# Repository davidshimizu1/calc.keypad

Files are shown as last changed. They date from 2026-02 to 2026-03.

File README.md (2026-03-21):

# Custom Calculator & Bluetooth Macropad



A portable 25-key embedded device built around the **ESP32-S3-WROOM-1-N8R8**, combining a scientific calculator, a fully customizable Bluetooth HID macropad, and real-time weather display — all on a single custom PCB with a 3D-printed enclosure.

---

## Features
- **Scientific Calculator** — Full expression evaluation via custom GUI
- **Bluetooth HID Macropad** — 25 keys with 47 fully customizable macro bindings via BLE
- **Real-Time Weather** — Fetches live temperature data from OpenWeatherMap over Wi-Fi
- **Dual-Radio** — Simultaneous Wi-Fi and BLE operation on a single board
- **3.5" HMI Display** — 480×320 touchscreen driven via UART with mode switching
- **LiPo Battery** — Onboard charging circuit with deep-sleep power optimization
- **<4ms HID Latency** — Interrupt-driven key matrix scanning for instantaneous input

---

---

## Demo

### Calculator Mode
https://github.com/user-attachments/assets/d92eaae9-ccc6-4540-ab36-3ccdf94c4ab0

### Macropad Mode
https://github.com/user-attachments/assets/1930882c-5ee2-4487-85e7-eceab5c94025

---

## Hardware

### Core Components
| Component | Details |
|---|---|
| MCU | ESP32-S3-WROOM-1-N8R8 (8MB Flash, 8MB PSRAM) |
| Display | 3.5" 480×320 HMI (UART) |
| Switches | Kalih Choc V1 Ambient Silent |
| Battery | 1000mAh LiPo battery|
| PCB | Custom 4-layer, designed in Altium Designer |
| Enclosure | Multi-part 3D printed (PA12-HP Nylon) |
| Display Module | https://www.buydisplay.com/3-5-inch-480x320-hmi-intelligent-smart-uart-spi-touch-ips-tft-lcd-display |
| *All PCB and 3D printed parts from JLCPCB.com |

### PCB Design
- 4-layer stackup with dedicated power and ground planes
- RF keep-out zones around ESP32-S3 antenna to prevent detuning
- Integrated LiPo charging circuit

📁 Altium design files available in `/PCB`

---

## Firmware Architecture

The firmware is structured as a **main file + multiple custom libraries**, each handling a distinct subsystem:

```
/
├── src/
│   └── main.cpp              # Main file, calls the libraries
├── lib/
│   ├── Calculator/           # Scientific calculator logic
│   ├── Keypad/               # Scans key matrix & BLE HID profile 
│   ├── NetworkManagement/    # Handles, BLE, WiFi, weather, and time
│   ├── Display/              # UART HMI display & GUI state machine
│   └── PowerManagement/      # Handles power management
├── lib/
│   ├── Config/               # Contains pin definitions, addresses and variables
```

### Key Design Decisions
- **Non-blocking architecture** — Wi-Fi REST requests and BLE HID run concurrently without latency interference
- **Interrupt-driven matrix scanning** — Achieves <4ms HID response time while minimizing CPU overhead
- **Deep-sleep optimization** — Reduces idle power draw to extend battery life
- **Modular state machine** — GUI toggles cleanly between calculator and macropad modes

---

## Technical Highlights

### RF Design
The ESP32-S3-WROOM-1 module requires careful PCB layout to maintain antenna performance. This design implements:
- Localized copper keep-out zones beneath the module antenna
- Dedicated RF ground plane on inner layer 2
- Physical separation of noisy switching circuits from the RF section

### Power Management
- Deep-sleep triggered after configurable idle timeout
- LiPo charging via onboard circuit (add IC part number here)
- Interrupt-driven wake from any keypress

### Display Communication
The HMI display is driven over UART using a custom GUI subsystem that manages two distinct screen states — calculator mode and macropad mode — with clean transitions between them.

---

## Project Structure
```
/
├── 3D_models/          # Fusion 360 CAD files (.step, .stl)
├── Code/               # All code for project
├── fab/                # fabrication files for PCB production
├── pcb/                # Schematic and PCB files
└── README.md
```

---

## Built With
- [Visual Studio Code](https://code.visualstudio.com/) / PlatformIO
- [Altium Designer](https://www.altium.com/) — PCB design
- [Fusion 360](https://www.autodesk.com/products/fusion-360/) — Enclosure design
- [UI Editor](https://www.buydisplay.com/3-5-inch-480x320-hmi-intelligent-smart-uart-spi-touch-ips-tft-lcd-display) - Design UI (specific for this display)
- [OpenWeatherMap API](https://openweathermap.org/api) — Weather data

---

## Author
**David Shimizu**
[LinkedIn](https://linkedin.com/in/davidshimizu) · [GitHub](https://github.com/davidshimizu1)

<!--
![IMG_0332](https://github.com/user-attachments/assets/3b640d5e-4a3a-493a-8fa4-46986a46d832)

https://github.com/user-attachments/assets/d92eaae9-ccc6-4540-ab36-3ccdf94c4ab0

https://github.com/user-attachments/assets/1930882c-5ee2-4487-85e7-eceab5c94025

![comparison](https://github.com/user-attachments/assets/92db343a-2714-455a-88ce-03647a39ccdb)

![sidecomparison](https://github.com/user-attachments/assets/7a27574d-f005-4f37-92e9-b8760f2ecc49)
-->

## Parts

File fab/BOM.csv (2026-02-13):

Comment | Description | Designator | Footprint | LibRef | Quantity | LCSC Part #
10uF | 0402 smd capacitor | C1, C5 | 0402 capacitor | 0402 capacitor | 2 | C15525
22uF | 0402 smd capacitor | C2, C3 | 0402 capacitor | 0402 capacitor | 2 | C105226
4u7 | 0402 smd capacitor | C4 | 0402 CAPACITOR | 0402 capacitor | 1 | C23733
10uF |  | C6, C7, C8 | 0603 CAPACITOR | 0603 capacitor | 3 | C19702
100nF | 0402 smd capacitor | C9, C10 | 0402 CAPACITOR | 0402 capacitor | 2 | C1525
SOD-323 | 1N4148WS | D1, D2, D3, D4, D5, D6, D7, D8, D9, D10, D11, D12, D13, D14, D15, D16, D17, D18, D19, D20, D21, D22, D23, D24, D25 | SOD-323 | SOD-323 | 25 | C2128
RLED | Red 0603 Light Emitting Diodes | D26, D28 | LED_KT-0603R | KT-0603R | 2 | C2286
SMF5.0AT1G | 200 W Transient Voltage Suppressor, 2-Pin SOD-123FL, Pb-Free, Tape and Reel | D27 | ONSC-SOD-123FL-2-498_V | CMP-1061-00612-1 | 1 | C19077497
SS14 | 40V Independent Type 1A 550mV@1A SMA(DO-214AC) Schottky Diodes ROHS | D29 | SMA(DO-214AC)(SCHOTTKY) | ss14 | 1 | C8678
ESP32-S3-WROOM-1-N8R8 |  | IC1 | ESP32-S3-WROOM-1-N8R8 | ESP32-S3-WROOM-1-N8R8 | 1 | C2913201
TP4056X | Integrated Circuit | IC2 | SOIC127P600X175-9N | TP4056X | 1 | C16581
TPS61023DRLR | Integrated Circuit | IC3 | SOTFL50P160X60-6N | TPS61023DRLR | 1 | C919459
battery connector |  | J1 | 2PIN WIRE TO BOARD | 2pin wire to board | 1
503480-2000 | 0.5 mm Pitch Easy-On(TM) BackFlip(TM) Type FPC Connector, 1.0 mm Mated Height, Right Angle, SMT, Dual Contact, 20 Circuits, -40 to 85 degC, ELV and RoHS Compliant, Tape and Reel | J2 | MOLX-503480-2000 | CMP-1241-00121-1 | 1 | C234192
2.2uH |  | L1 | 0603 INDUCTOR | 0603 inductor | 1 | C98327
1uH |  | L2 | 0802 inductor | 0805 inductor | 1 | C1042
m2 mounting hole |  | MH1, MH2, MH3, MH4, MH5 | m2 mounting hole | m2 mounting hole | 5
AO3401A | P-Channel MOSFET, 30 V, 4 A, -55 to 150 degC, 3-Pin SOT-23-3L, RoHS, Tape and Reel | Q2 | AO-SOT-23-3L_V | CMP-2000-05778-1 | 1 | C15127
4k7 |  | R1, R2, R3, R4, R5 | 0603 RESISTOR | 0603 resistor | 5 | C23162
732K |  | R6 | 0402 resistor | 0402 resistor | 1 | C5159692
100K |  | R7 | 0402 resistor | 0402 resistor | 1 | C25741
10K |  | R8, R14, R15, R16, R19 | 0603 RESISTOR | 0603 resistor | 5 | C25804
1K |  | R9, R17 | 0402 RESISTOR | 0402 resistor | 2 | C11702
100K |  | R10 | 0603 RESISTOR | 0603 resistor | 1 | C25803
5K1 |  | R11, R12 | 0603 RESISTOR | 0603 resistor | 2 | C23186
22K |  | R13 | 0603 RESISTOR | 0603 resistor | 1 | C31850
1k2 |  | R18 | 0603 RESISTOR | 0603 resistor | 1 | C22765
switch |  | SW1, SW2, SW3, SW4, SW5, SW6, SW7, SW8, SW9, SW10, SW11, SW12, SW13, SW14, SW15, SW16, SW17, SW18, SW19, SW20, SW21, SW22, SW23, SW24, SW25 | CHOCV1 | switch | 25
push button |  | SW26, SW27 | PUSH BUTTON | push button | 2 | C318884
TLV62569DBVR | IC REG BUCK ADJ 2A SOT23-5 | U1 | FP-DBV0005A-MFG | CMP-04918-000387-1 | 1 | C141836
usbc connector |  | USB1 | USBC CONNECTOR | usbc connector | 1 | C2765186
USBLC6-2SC6 |  | X1 | STM-SOT23-6L_V | USBLC6-2SC6 | 1 | C7519

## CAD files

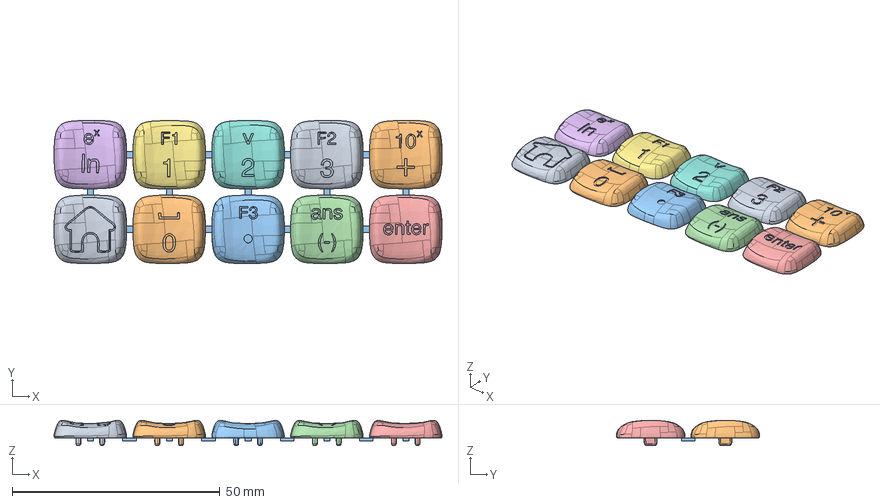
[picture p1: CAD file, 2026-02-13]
3d_models/ROW 1 ROW 2.step
93.5 x 34.5 x 6.10 mm
blank v3
blank v3_1
blank v3_2
blank v3_3
blank v3_4
blank v3_5
blank v3_6
blank v3_7
blank v3_8

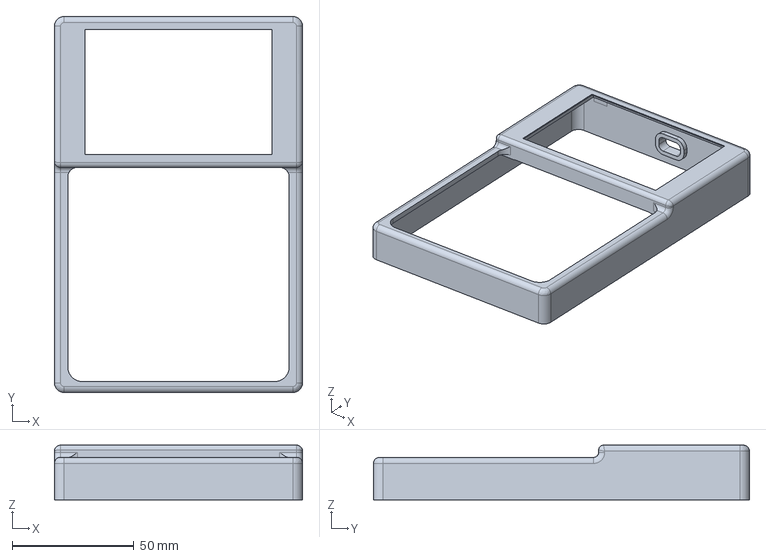
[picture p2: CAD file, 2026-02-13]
3d_models/top.step
102.0 x 154.5 x 22.5 mm

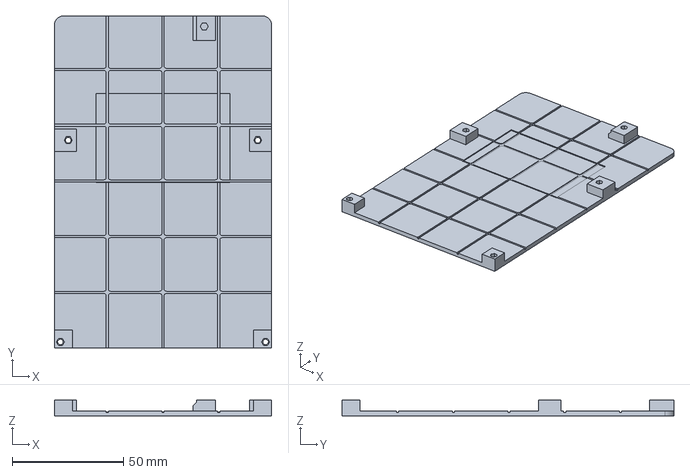
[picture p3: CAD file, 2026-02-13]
3d_models/bottom.step
97.4 x 148.9 x 7.10 mm

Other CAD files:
3d_models/ROW 5 BLANK ROW.step
3d_models/ROW 3 ROW 4 .step
3d_models/bottom.stl
3d_models/top.stl

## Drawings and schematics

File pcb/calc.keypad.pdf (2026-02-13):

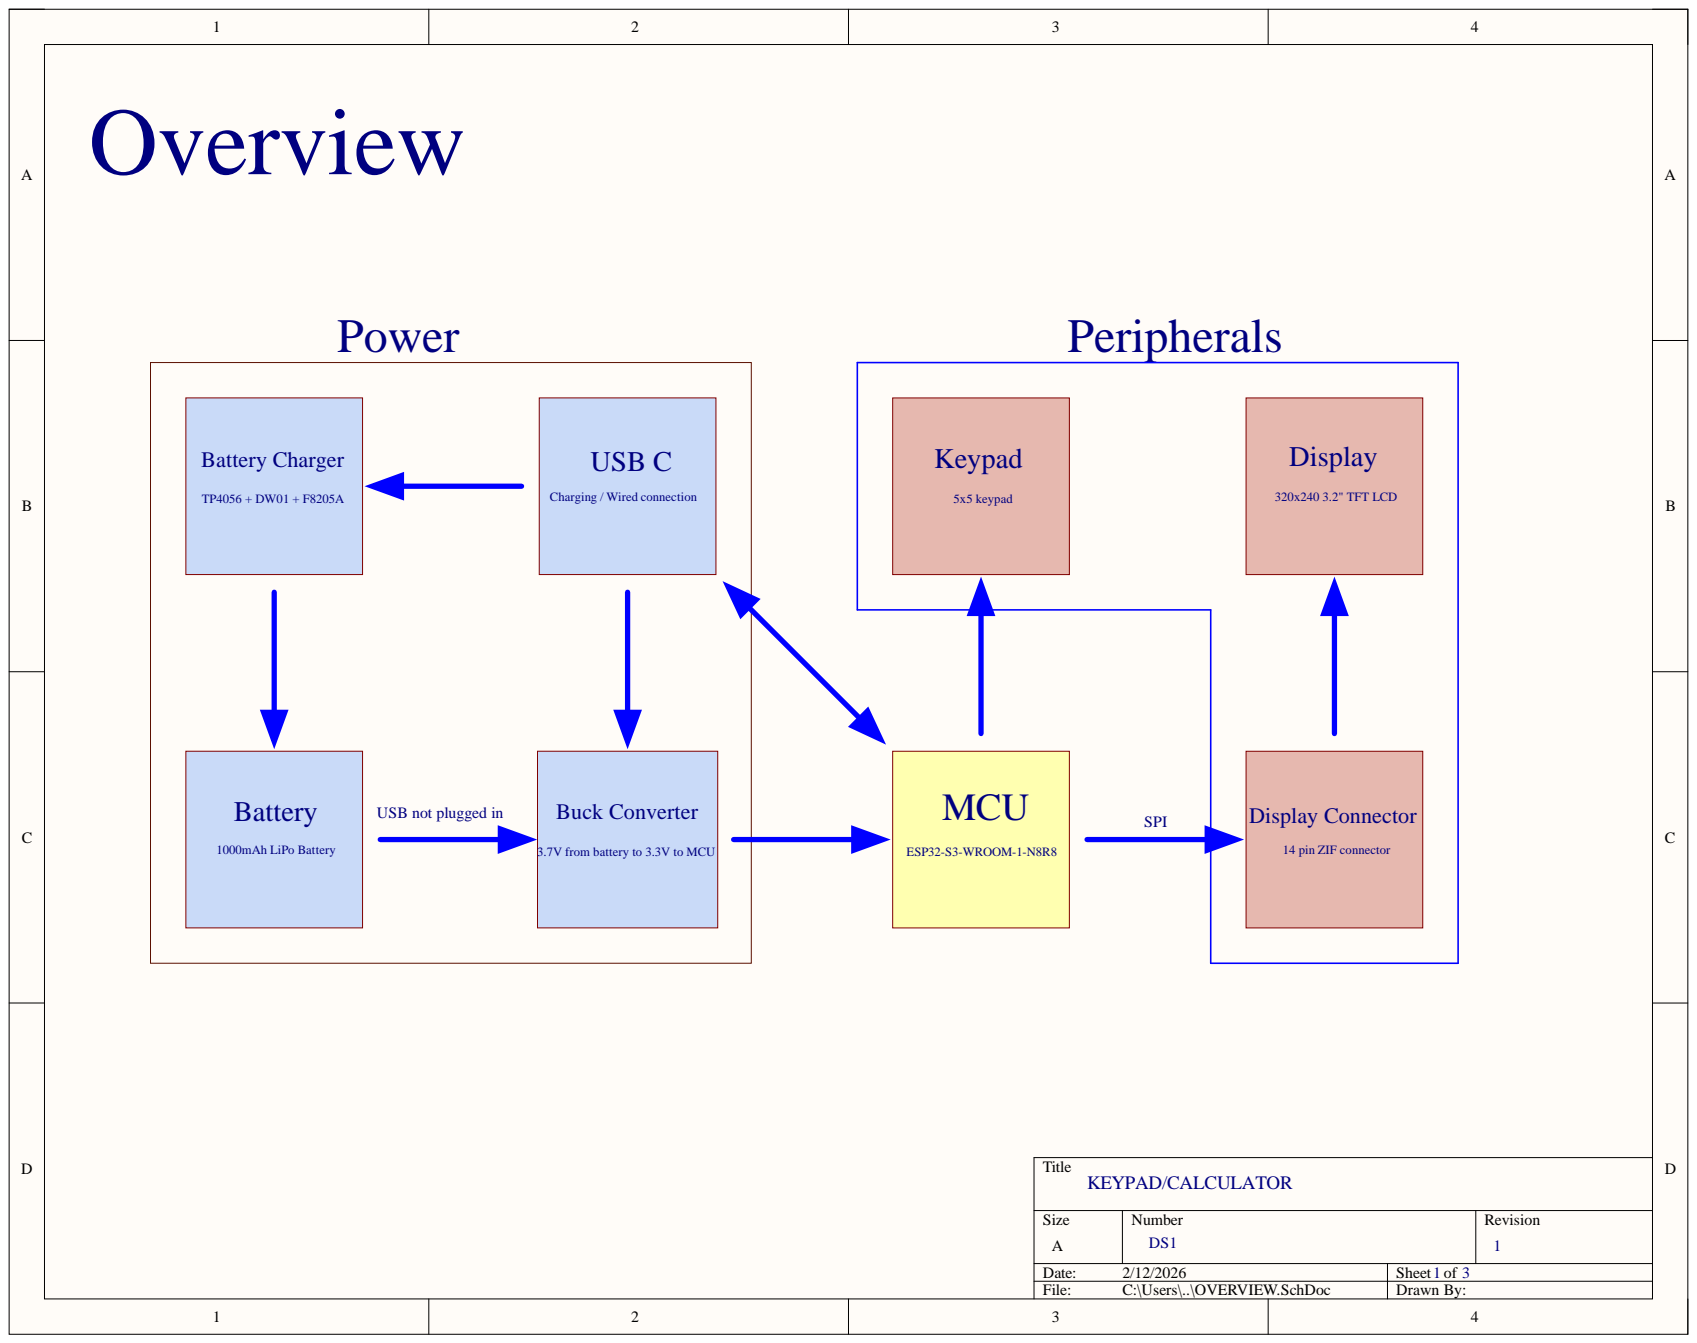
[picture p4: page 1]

USB not plugged in

3.7V from battery to 3.3V to MCU

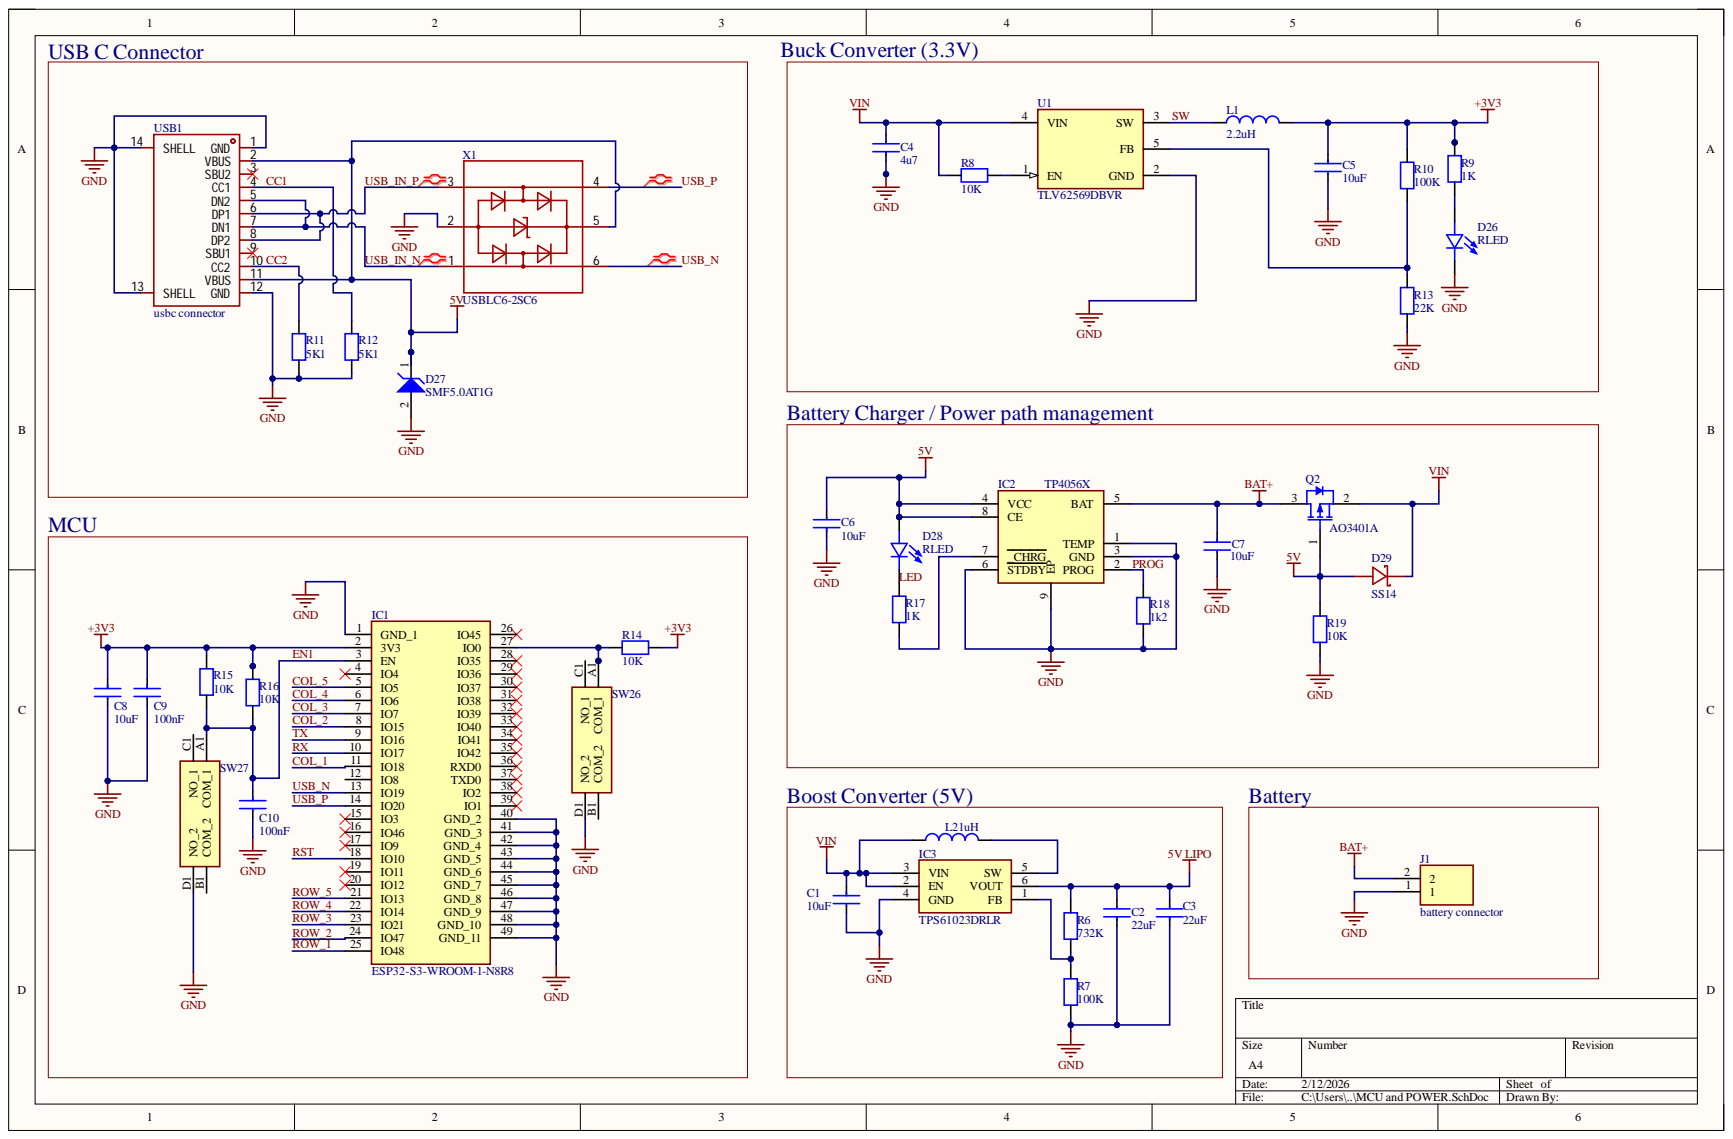
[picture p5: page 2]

1 1
1 2

9 | 3 4
1 0 | 3 5

Size A 4 | N u mb er | Rev isi o n

Date: 2 / 1 2 /2 0 2 6 | Sheet o f
Fi le: C : \Users\ . . \M C U an d PO WER .Sc h D o c | D raw n B y :

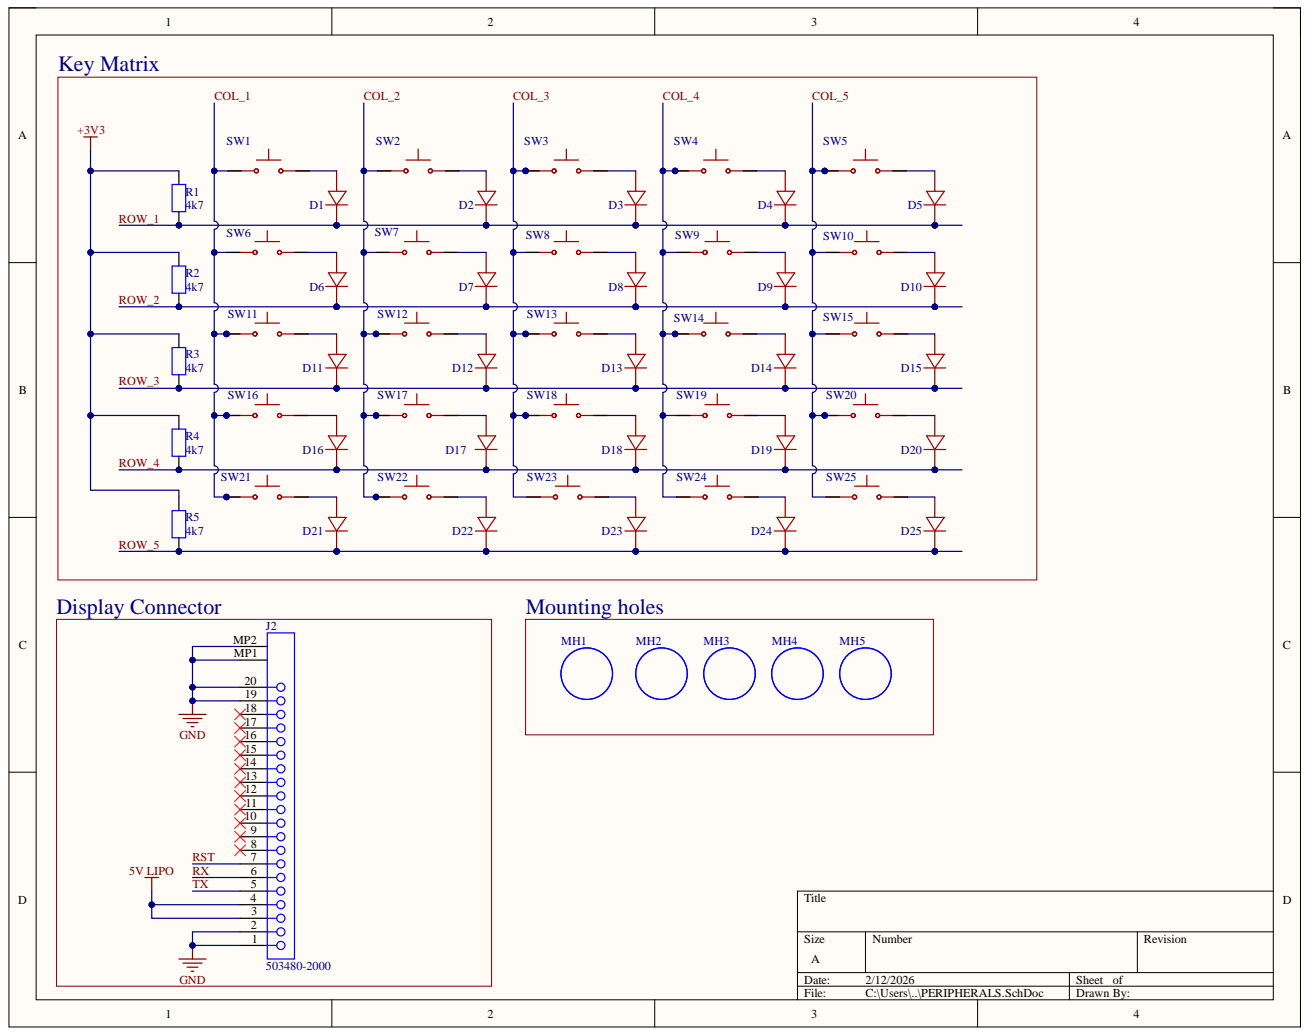
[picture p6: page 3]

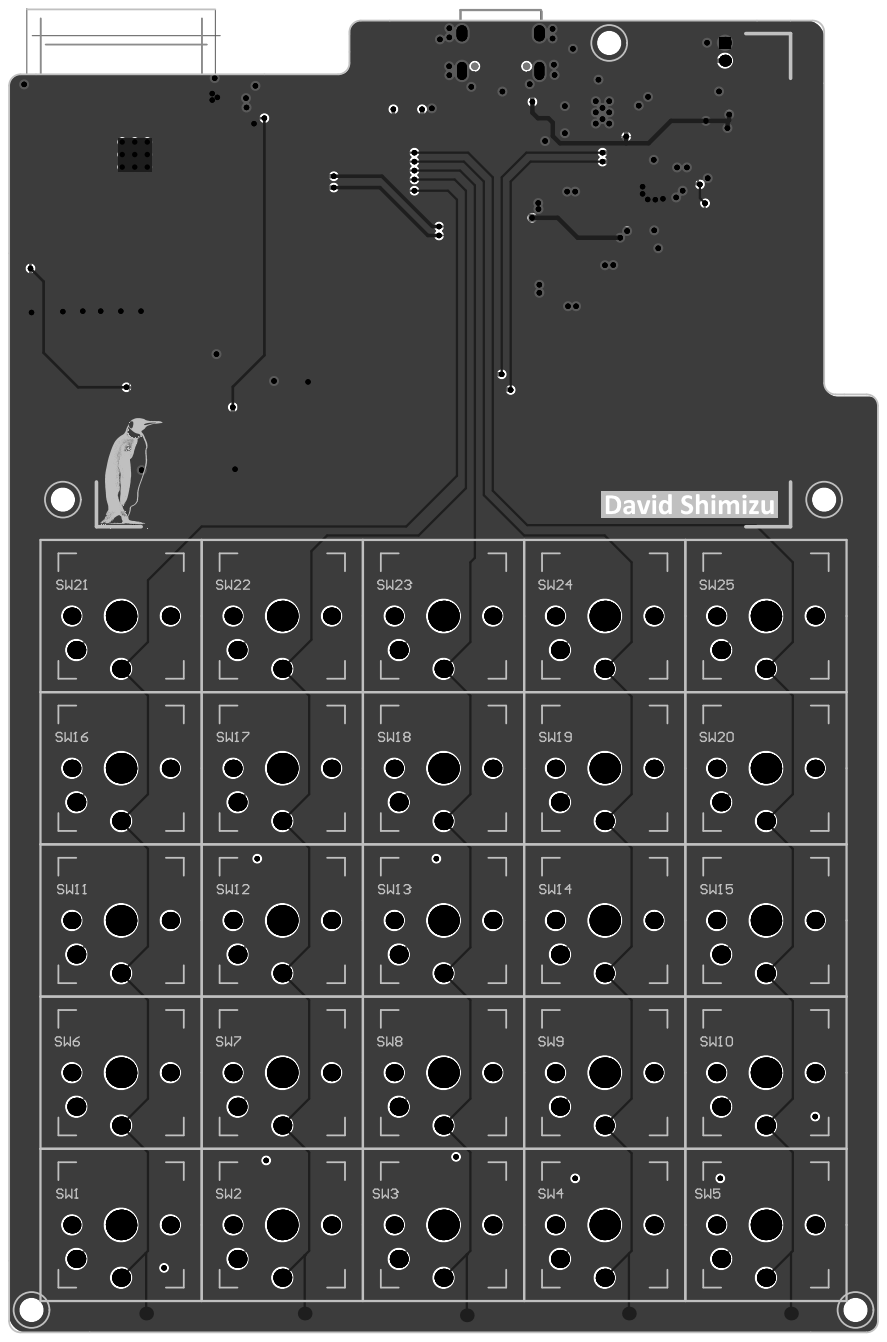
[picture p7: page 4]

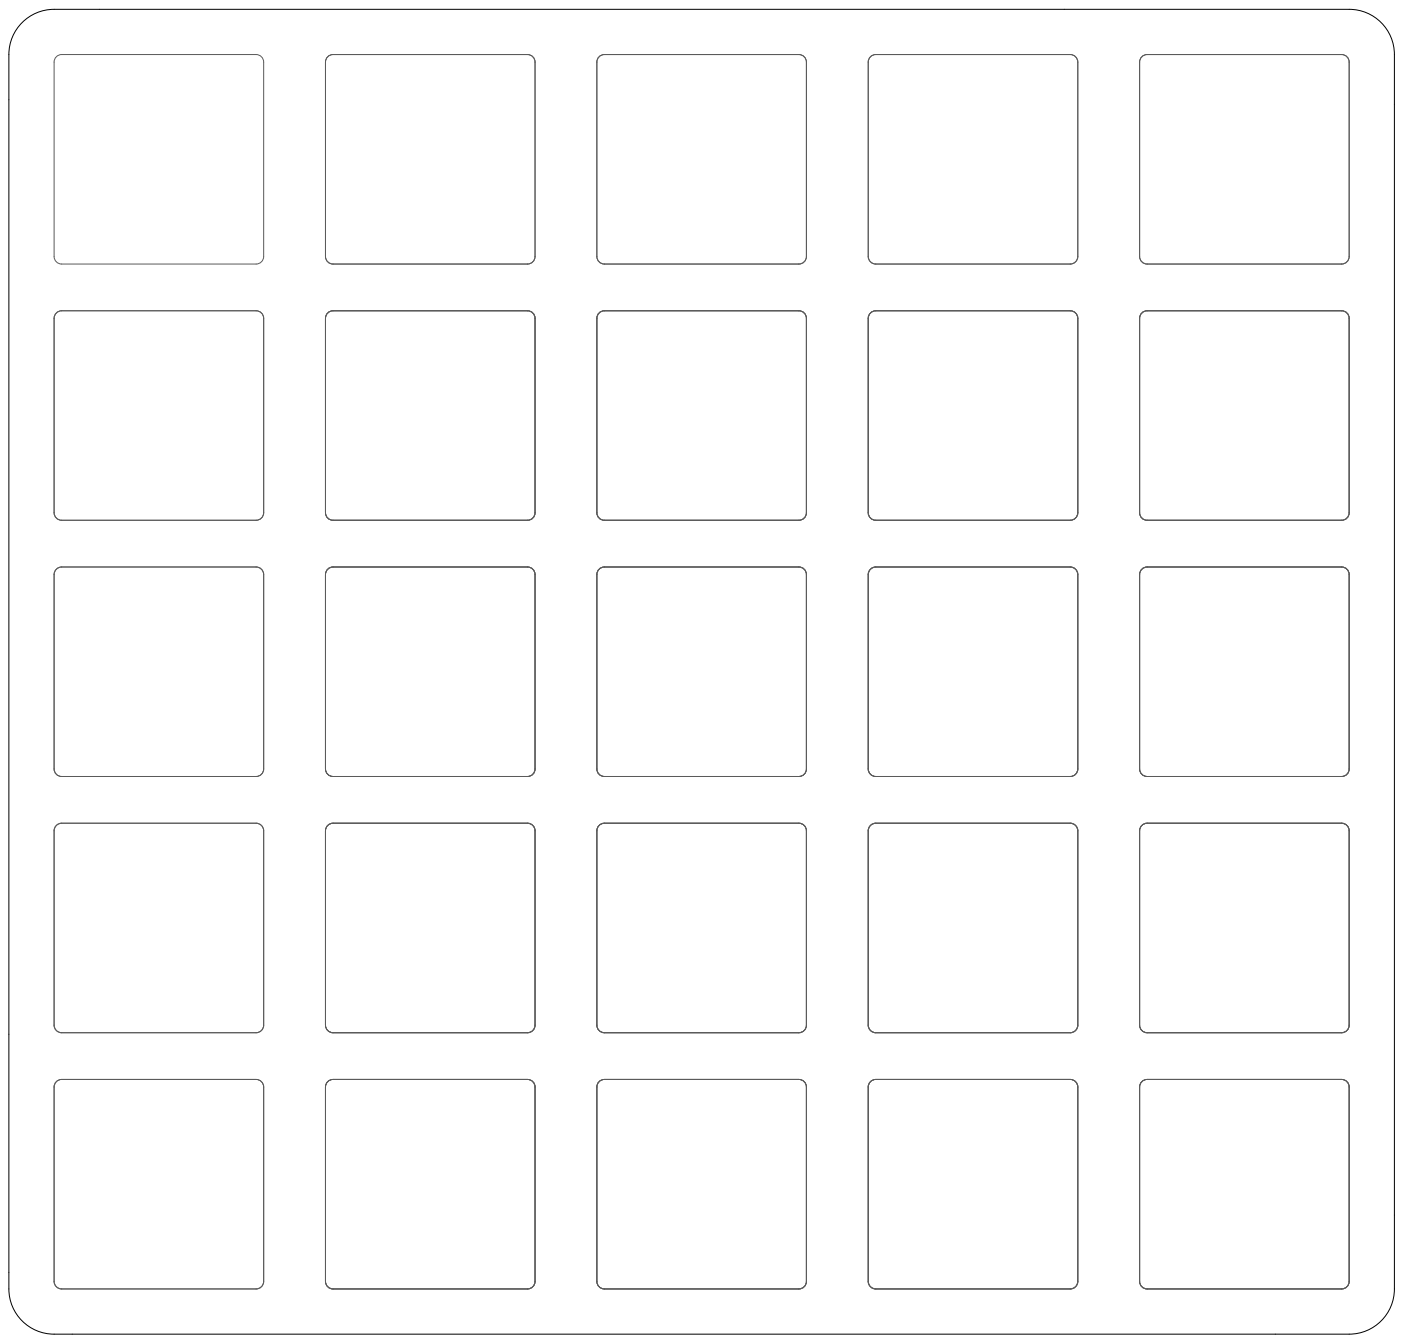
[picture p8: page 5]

Comment | Description | Designator | Footprint | LibRef | Quantity
10uF | 0402smd capacitor | C1, C5 | 0402capacitor | 0402capacitor | 2
22uF | 0402smd capacitor | C2, C3 | 0402capacitor | 0402capacitor | 2
4u7 | 0402smd capacitor | C4 | 0402capacitor | 0402capacitor | 1
10uF | | C6, C7, C8 | 0603CAPACITOR | 0603capacitor | 3
100nF | 0402smd capacitor | C9, C10 | 0402capacitor | 0402capacitor | 2
SOD-323 | 1N4148WS | D1, D2, D3, D4, D5, D6, D7, D8, D9, D10, D11, D12, D13, D14, D15, D16, D17, D18, D19, D20, D21, D22, D23, D24, D25 | SOD-323 | SOD-323 | 25
RLED | Red 0603Light EmittingDiodes | D26, D28 | LED_KT-0603R | KT-0603R | 2
SMF5.0AT1G | 200WTransient VoltageSuppressor, 2-Pin SOD-123FL, Pb-Free, Tapeand Reel | D27 | ONSC-SOD-123FL-2-498_V | CMP-1061-00612-1 | 1
SS14 | 40VIndependent Type 1A550mV@1A SMA(DO-214AC) SchottkyDiodes ROHS | D29 | SMA(DO-214AC)(schottky) | ss14 | 1
ESP32-S3-WROOM-1-N8R8 | | IC1 | ESP32-S3-WROOM-1-N8R8 | ESP32-S3-WROOM-1-N8R8 | 1
TP4056X | Integrated Circuit | IC2 | SOIC127P600X175-9N | TP4056X | 1
TPS61023DRLR | Integrated Circuit | IC3 | SOTFL50P160X60-6N | TPS61023DRLR | 1
battery connector | | J1 | 2pin wire to board | 2pin wire to board | 1
503480-2000 | 0.5mm Pitch Easy-On(TM) BackFlip(TM) TypeFPCConnector, 1.0mm Mated Height, Right Angle, SMT, Dual Contact, 20 Circuits, -40to 85 degC, ELVand RoHS Compliant, Tapeand Reel | J2 | MOLX-503480-2000 | CMP-1241-00121-1 | 1
2.2uH | | L1 | 0603inductor | 0603inductor | 1
1uH | | L2 | 0802inductor | 0805inductor | 1
m2mountinghole | | MH1, MH2, MH3, MH4, MH5 | m2mountinghole | m2mountinghole | 5
AO3401A | P-Channel MOSFET, 30V, 4A, -55to 150 degC, 3-Pin SOT-23-3L, RoHS, Tapeand Reel | Q2 | AO-SOT-23-3L_V | CMP-2000-05778-1 | 1
4k7 | | R1, R2, R3, R4, R5 | 0603resistor | 0603resistor | 5
732K | | R6 | 0402resistor | 0402resistor | 1
100K | | R7 | 0402resistor | 0402resistor | 1
10K | | R8, R14, R15, R16, R19 | 0603resistor | 0603resistor | 5
1K | | R9, R17 | 0402resistor | 0402resistor | 2
100K | | R10 | 0603resistor | 0603resistor | 1
5K1 | | R11, R12 | 0603resistor | 0603resistor | 2
22K | | R13 | 0603resistor | 0603resistor | 1
1k2 | | R18 | 0603resistor | 0603resistor | 1
switch | | SW1, SW2, SW3, SW4, SW5, SW6, SW7, SW8, SW9, SW10, SW11, SW12, SW13, SW14, SW15, SW16, SW17, SW18, SW19, SW20, SW21, SW22, SW23, SW24, SW25 | chocv1 | switch | 25
push button | | SW26, SW27 | push button | push button | 2
TLV62569DBVR | ICREGBUCKADJ2A SOT23-5 | U1 | FP-DBV0005A-MFG | CMP-04918-000387-1 | 1
usbc connector | | USB1 | USBCconnector | usbc connector | 1
USBLC6-2SC6 | | X1 | STM-SOT23-6L_V | USBLC6-2SC6 | 1

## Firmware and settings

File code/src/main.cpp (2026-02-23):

#include <Arduino.h>
#include "Config.h"
#include "Calculator.h"
#include "HMI_Driver.h"
#include "Keypad.h"
#include "WifiManager.h"
#include "Clock.h"
#include "BluetoothManager.h"
#include "Weather.h"

ExpressionParser parser;
HMIDriver hmi;
KeypadScanner keypad;
WifiManager myNet;
ClockManager myClock(Serial2);
BLEManager bleManager;
WeatherManager weather(Serial2, myNet);

enum OperatingMode {
    MODE_CALCULATOR,
    MODE_KEYPAD
};

OperatingMode currentMode = MODE_CALCULATOR; 

String inputBuffer = ""; 
double lastResult = 0.0;
bool hasLastResult = false;
CalcHistory history[3]; 

void pushHistory(String eq, double val);
void handleCalculatorLogic(const String& keyStr);
void switchHmiPage(uint8_t pageId);

void setup() {
    Serial.begin(115200);
    Serial2.begin(115200, SERIAL_8N1, HMI_RX, HMI_TX);
    delay(2000);
    
    Serial.println("Starting System...");
    Serial.flush();
    
    Serial.println("Initializing Time...");
    myClock.begin();

    if (myNet.connect()) { 
        myClock.sync(); 
        myNet.disconnect(); 
    }

    myNet.disconnect();
    delay(500);
    bleManager.begin();

    keypad.begin(ROW_PINS, COL_PINS);
    hmi.begin(&Serial2);
    bleManager.begin();

    hmi.addr_input = ADDR_INPUT_VP;
    hmi.addr_eq_1  = ADDR_EQ_1;
    hmi.addr_ans_1 = ADDR_ANS_1;
    hmi.addr_eq_2  = ADDR_EQ_2;
    hmi.addr_ans_2 = ADDR_ANS_2;
    hmi.addr_eq_3  = ADDR_EQ_3;
    hmi.addr_ans_3 = ADDR_ANS_3;

    hmi.updateInput("");
    hmi.updateHistory(history[0], history[1], history[2]);
    switchHmiPage(0);

    weather.begin();
    
    Serial.println("System Ready. Operating Mode: CALCULATOR");
}

void loop() {
    const char* key = keypad.getKey();
    
    myClock.update();
    weather.update();
    
    if (!key) return;
    
    String keyStr = String(key);

    if (keyStr == "home") {
        if (currentMode == MODE_CALCULATOR) {
            currentMode = MODE_KEYPAD;
            Serial.println("Switched Mode -> BLUETOOTH KEYPAD");
            switchHmiPage(1); 
        } else {
            currentMode = MODE_CALCULATOR;
            Serial.println("Switched Mode -> LOCAL CALCULATOR");
            switchHmiPage(0);
        }
        return; 
    }

    if (currentMode == MODE_KEYPAD) {
        bleManager.sendKey(keyStr);
    } else {
        handleCalculatorLogic(keyStr);
    }
}
    // switch mode
void switchHmiPage(uint8_t pageId) {
    try {
        uint8_t cmd[] = {
            0x5A, 0xA5,
            0x05,
            0x10,
            0x70,
            0x00,
            0x00,
            pageId 
        };
        Serial2.write(cmd, sizeof(cmd));
    } catch (...) {
        Serial.println("CRITICAL: Failed to sync UI page state over UART.");
    }
}
    // calculator history
void pushHistory(String eq, double val) {
    history[0] = history[1]; 
    history[1] = history[2];
    history[2].equation = eq;
    String ansStr = String(val, 8);

    while (ansStr.endsWith("0")) ansStr.remove(ansStr.length() - 1);
    if (ansStr.endsWith(".")) ansStr.remove(ansStr.length() - 1);
    
    history[2].answer = "= " + ansStr;
    
    hmi.updateHistory(history[0], history[1], history[2]);
}
    // calculator logic
void handleCalculatorLogic(const String& keyStr) {
    if (keyStr == "SHIFT_CMD") {
        bool active = keypad.isShiftActive();
        Serial.print("Shift Active: "); Serial.println(active);
        return; 
    }

    if (keyStr == "clr") {
        inputBuffer = "";
        hmi.updateInput(inputBuffer);
        return;
    }

    if (keyStr == "del") {
        if (inputBuffer.length() > 0) {
            inputBuffer.remove(inputBuffer.length() - 1);
            hmi.updateInput(inputBuffer);
        }
        return;
    }
/*
    if (keyStr == "home") {
        inputBuffer = "";
        history[0] = {"", ""};
        history[1] = {"", ""};
        history[2] = {"", ""};
        hasLastResult = false;
        hmi.updateHistory(history[0], history[1], history[2]);
        hmi.updateInput(inputBuffer);
        return;
    }
*/
    if (keyStr == "enter") {
        if (inputBuffer.length() > 0) {
            double result = parser.solve(inputBuffer);
            pushHistory(inputBuffer, result);
            lastResult = result;
            hasLastResult = true;
            inputBuffer = "";
            hmi.updateInput(inputBuffer);
        }
        return;
    }

    if (keyStr == "up" || keyStr == "down" || keyStr == "left" || keyStr == "right" ||
        keyStr == "F2" || keyStr == "F3"   || keyStr == "F4") {
        return;
    }
    if (inputBuffer == "" && hasLastResult) {
        if (keyStr == "+" || keyStr == "-" || keyStr == "*" || keyStr == "/" || keyStr == "^") {
            String resStr = String(lastResult);
            if (resStr.endsWith(".00")) resStr.remove(resStr.length() - 3);
            inputBuffer = resStr;
        }
    }

    if (keyStr == "neg") {
        inputBuffer += "-";
    }
    else if (keyStr == "ans") {
        if (hasLastResult) inputBuffer += String(lastResult);
    }
    else if (keyStr == "10^x") {
        inputBuffer += "10^(";
    }
    else if (keyStr == "sin" || keyStr == "cos" || keyStr == "tan" || 
             keyStr == "asin"|| keyStr == "acos"|| keyStr == "atan"||
             keyStr == "ln"  || keyStr == "log" || keyStr == "sqrt" || 
             keyStr == "exp") {
        inputBuffer += keyStr + "(";
    }
    else {
        inputBuffer += keyStr;
    }

    hmi.updateInput(inputBuffer);
}

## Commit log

2026-02-22 Fix weather not fetching or updating the display
    WeatherManager was never instantiated in main.cpp, and WiFi was
    disconnected before any fetch could occur. Added WeatherManager to
    main.cpp, wired it to WifiManager so fetchWeather() connects and
    disconnects WiFi itself, and calls begin()/update() in setup/loop.
    [main.cpp]
2026-02-23 add home button
